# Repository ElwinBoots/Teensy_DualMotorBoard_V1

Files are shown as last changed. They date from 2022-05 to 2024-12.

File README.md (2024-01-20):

This project aims to deliver high performance (fast loops > 40 kHz, fast motion, and small following errors) brushless motor control.

## Videos in action 
See: https://www.youtube.com/@elwinboots2614

## Hardware 
- 1 Simple custom PCB for making connections
- 1 Teensy 4.1
- 2 DRV8301 motor drive boards, see Aliexpress
- 2 BLDC motors (sensorless or ABI encoders)
- 4 Pololu ACS711EX current sensor boards (drive boards have low side sensors. Prefer to use these instead to have in line sensing)

## Firmware
See firmware folder. Almost all code can be found in Firmware.ino. 

### Software to build firmware
"Old" Arduino IDE
- Arduino IDE 1.8.19 https://www.arduino.cc/en/software (Legacy IDE)
- Teensyduino https://www.pjrc.com/teensy/td_download.html (Follow the "Arduino 1.8.x Software Development" steps)
Or,
"New" Arduino IDE:
- Arduino IDE https://www.arduino.cc/en/software (current version: 2.2.1)
- Teensyduino https://www.pjrc.com/teensy/td_download.html (Follow the "Arduino 2.0.x Software Development" steps
 
If you want to test with 1 or 0 DRV8301 boards connected, search for the line: SPI_init( SSPIN ); and/or SPI_init( SSPIN2 ); and comment them out. With these lines commented the firmware and software can run without boards. With these lines the board waits for the DRV8301 boards, before continuing to boot.

Almost all parameters are defined in defines.h. All of these are accessible (read and write) from the host pc using the software provided. 

To add a variable and make it accessible from the PC:
1. Add parameter in defines.h 
2. run "gentracefile (Run this to update trace.h).bat". 
3. Compile and download Firmware.ino in Arduino IDE

Note: I use the 816 Mhz (overclock) option in the CPU speed menu.

## Software
- Python 3.x
- Spyder
- Code in Software folder

### To install: 
1. Download latest version of Python: https://www.python.org/downloads/
2. Install Python
3. In a command window, run `pip install spyder`
4. Run Spyder (C:\Users\XXX\AppData\Local\Programs\Python\PythonXXX\Scripts\spyder.exe)

### To use: 
1. In Spyder, run first cell (ctrl + enter) in test_object.py (for any missing modules, run `pip install <modulename>` in a cmd window.
2. When a Teensy is found with the correct firmware, you should get: "Connected to Teensy on COMX with serial number: XXXXXXXX."
3. Check that the LED on the Teensy is off. If it is still on, make check connection and power to DRV8301 boards, or comment out SPI_init( SSPIN ); and/or SPI_init( SSPIN2 ) to test without DRV8301 boards.
4. Now you can type `motor` in the IPython console, and it should show all parameters:\
afbeelding

5. To see for example only the configuration of motor 1, you can type `motor.conf1`:\
afbeelding

6. To retreive a single variable, just type the variable name and click enter. Example: `motor.state1.encoderPos1`. Note that you can use `tab` to autocomplete the name of a variable.
7. To set a variable, simply write a value to it. Example: `motor.conf1.commutationoffset = 0`, or use `m.setpar('motor.conf1.commutationoffset',0)`\
afbeelding\
The setting of variables is fast. Almost 20000 values can be written in 1 second when writing one by one (even more when using arrays):\
afbeelding

### Tracing
To trace variables/signals: 
1. Use m.setTrace() to select signals. Example: `m.setTrace([ 'motor.state1.emech' , 'motor.state1.rmech' , 'motor.state1.ymech' ])`
2. Use `df = m.trace(2)` to trace for 2 seconds.
3. To plot, use `df.plot()`

Note1: By default tracing occurs at the full sample rate. Up to 50 signals at 60 kHz is possible. Downsampling is also possible to reduce load.\
Note2: All communication is in binary. This means that no precision is lost in the tracing.

### Tracing (background)
For non-blocking tracing of variables/signals:
1. Use m.setTrace() to select signals. Example: `m.setTrace([ 'motor.state1.emech' , 'motor.state1.rmech' , 'motor.state1.ymech' ])`
2. Use `m.tracebg( )` to start a background trace.
3. Use `df = m.stoptracegetdata()` to stop the trace and get the data
4. To plot, use `df.plot()`

Note: during the tracing you can still set variables. You can however not retrieve other variables.

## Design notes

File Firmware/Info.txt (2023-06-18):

/*
  See https://nl.mathworks.com/help/mcb/ref/mtpacontrolreference.html for a PMSM model

  vd = id*R + dλd/dt − ωe * Lq * iq
  vq = iq*R + dλq/dt + ωe * Ld * id + ωe * λpm
  λd = Ld * id + λpm
  λq = Lq * iq
  Te = 1.5* N_pp * (λpm * iq+(Ld− Lq) * id * iq)

  vd is the d-axis voltage (Volts).
  vq is the q-axis voltage (Volts).
  id is the d-axis current (Amperes).
  iq is the q-axis current (Amperes).
  R is the stator phase winding resistance (Ohms).
  λpm is the permanent magnet flux linkage (Weber).
  λd is the d-axis flux linkage (Weber).
  λq is the q-axis flux linkage (Weber).
  ωe is the electrical speed corresponding to frequency of stator voltages (Radians/ sec).
  Ld is the d-axis winding inductance (Henry).
  Lq is the q-axis winding inductance (Henry).
  Te is the electromechanical torque produced by the PMSM (Nm).
  N_pp is the number of motor pole pairs.

  Te = 1.5* N_pp * (λpm * iq+(Ld− Lq) * id * iq)
  id = 0 -> Te = 1.5 * N_pp * λpm * iq [Nm]

  Kt_Nm_Apeak = 1.5 * N_pp * λpm                                            [Nm/Apeak]
  Kt_Nm_Arms = sqrt(2) * Kt_Nm_Apeak                                        [Nm/Arms]

  λpm = Kt_Nm_Apeak / (1.5 * N_pp) = Kt_Nm_Arms / (sqrt(2) * 1.5 * N_pp )   [Weber]

  Ke_phase_0_peak = N_pp * λpm
*/

/*
  With 1 motor:

  M:
  FLEXPWM2 4 5 6
  {1, M(2, 0), 1, 1},  // FlexPWM2_0_A   4  // EMC_06
  {1, M(2, 1), 1, 1},  // FlexPWM2_1_A   5  // EMC_08
  {1, M(2, 2), 1, 2},  // FlexPWM2_2_A   6  // B0_10

  Encoders:
  E1:
  0 1 3

  E2:
  30 31 33

  For two motors:

  M1:
  FLEXPWM4 22 23 2
  {1, M(4, 0), 1, 1},  // FlexPWM4_0_A  22  // AD_B1_08    --> M1 Phase B
  {1, M(4, 1), 1, 1},  // FlexPWM4_1_A  23  // AD_B1_09    --> M1 Phase C 
  {1, M(4, 2), 1, 1},  // FlexPWM4_2_A   2  // EMC_04      --> M1 Phase A

  M2:
  FLEXPWM2 4 5 6
  {1, M(2, 0), 1, 1},  // FlexPWM2_0_A   4  // EMC_06      --> M2 Phase C
  {1, M(2, 1), 1, 1},  // FlexPWM2_1_A   5  // EMC_08      --> M2 Phase B
  {1, M(2, 2), 1, 2},  // FlexPWM2_2_A   6  // B0_10       --> M2 Phase A

  Encoders:
  E1:
  0 1 3

  E2:
  30 31 33

  teensy 4.1 has 0..41 full size pins.

  Encoder possible on:
  0, 1, 2, 3, 4, 5, 7, 30, 31, 33, 36 and 37.
  WARNING! Pins 0, 5 and 37 share the same internal crossbar connections and are as such exclusive...pick one or the other.

//There are 4 hardware quadrature encoder channels available the Teensy 4.x.
//The Teensy 4.1 Encoders are supported on pins: 0, 1, 2, 3, 4, 5, 7, 30, 31, 33, 36 and 37.
//WARNING! Pins 0, 5 and 37 share the same internal crossbar connections and are as such exclusive...pick one or the other.
//Same thing applies to pins 1 / 36 and 5 / 37.

  ADC channel, pin numbers

    Note: 0 to 13 is same as 14 to 27. Do not try to use these for analog in!
        7,      // 0/A0  AD_B1_02   ENC1_A
        8,      // 1/A1  AD_B1_03   ENC1_B
        12,     // 2/A2  AD_B1_07   M1 out A INH-A
        11,     // 3/A3  AD_B1_06   ENC1_I
        6,      // 4/A4  AD_B1_01   M2 out C INH-C2
        5,      // 5/A5  AD_B1_00   M2 out B INH-B2
        15,     // 6/A6  AD_B1_10   M2 out A INH-A2
        0,      // 7/A7  AD_B1_11   M2 Ia              --> Orignial design --> Doesn't work
        13,     // 8/A8  AD_B1_08   M2 Ib              --> Orignial design --> Doesn't work
        14,     // 9/A9  AD_B1_09   M2 Ic              --> Orignial design --> Doesn't work
        255,  // 10/A10 AD_B0_12   -
        255,  // 11/A11 AD_B0_13    SDI (SPI)
        3,      // 12/A12 AD_B1_14  SDO (SPI)
        4,      // 13/A13 AD_B1_15  SCLK (SPI)

        7,      // 14/A0  AD_B1_02  M1 Ic
        8,      // 15/A1  AD_B1_03  M1 Ib
        12,     // 16/A2  AD_B1_07  M1 Ia
        11,     // 17/A3  AD_B1_06  M1 Vbus
        6,      // 18/A4  AD_B1_01  M1 EMF-A
        5,      // 19/A5  AD_B1_00  M1 EMF-B
        15,     // 20/A6  AD_B1_10  M1 EMF-C
        0,      // 21/A7  AD_B1_11  M2 Vbus
        13,     // 22/A8  AD_B1_08  M1 out C INH-C
        14,     // 23/A9  AD_B1_09  M1 out B INH-B
        255,    // 24/A10 AD_B0_12  M2 EMF-A  --> Exchanged for M2 Ia
        255,    // 25/A11 AD_B0_13  M2 EMF-B
        3,      // 26/A12 AD_B1_14  M2 EMF-C  --> Exchanged for M2 Ib
        4,      // 27/A13 AD_B1_15  M2 nOCTW
        255,    // 28               M2 PWRGD
        255,    // 29
        255,    // 30               ENC2_A
        255,    // 31               ENC2_B
        255,    // 32
        255,    // 33               ENC2_I
        255,    // 34               M1 EN-GATE
        255,    // 35               M1 nSCS
        255,    // 36               M1 nFAULT
        255,    // 37               M1 nOCTW
        1,      // 38/A14 AD_B1_12  M1 PWRGD
        2,      // 39/A15 AD_B1_13  M2 EN-GATE
        9,      // 40/A16 AD_B1_04  M2 nSCS
        10,     // 41/A17 AD_B1_05  M2 nFAULT

    Actual chain:
        12,     // 16/A2  AD_B1_07  M1 Ia
        8,      // 15/A1  AD_B1_03  M1 Ib

        1,      // 24/A10 AD_B0_12  M2 EMF-A  --> Exchanged for M2 Ia  // Analog channel 1 input 1 NOTE: only on ADC1
        3,      // 26/A12 AD_B1_14  M2 EMF-C  --> Exchanged for M2 Ib  // Analog channel 2 input 3 NOTE: only on ADC2

        11,     // 17/A3  AD_B1_06  M1 Vbus
        0,      // 21/A7  AD_B1_11  M2 Vbus
  */

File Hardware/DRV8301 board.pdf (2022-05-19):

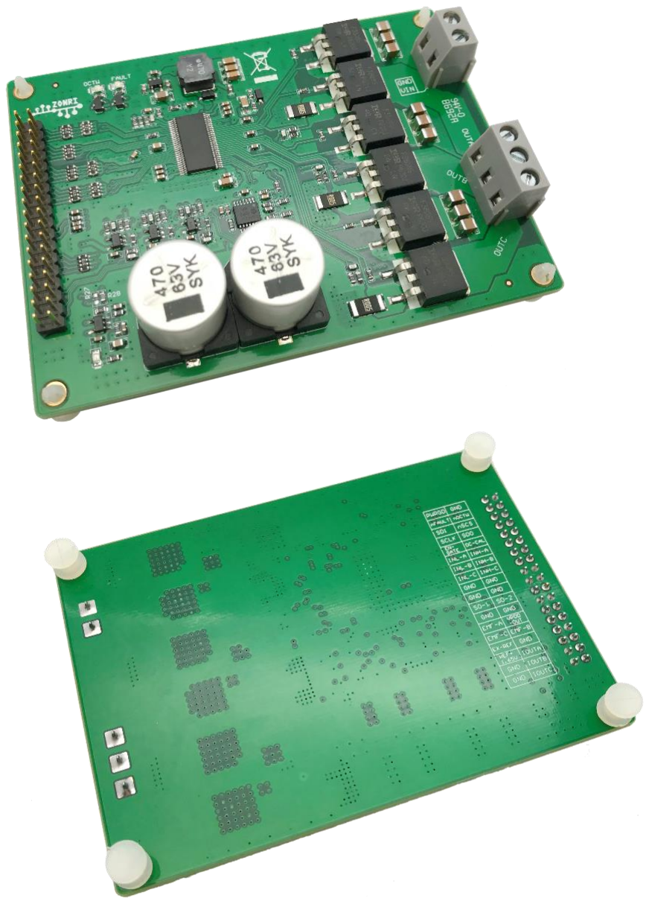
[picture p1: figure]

# DRV8301 电机驱动模块说明书

概述:

# - 额定电源输入范围:5.5V – 45Vdc，输出额定驱动电流 15A（室温下无安装散热器）。 - 板载三相外部电流放大电路，增益为 12.22，全幅度电流为±27A。 - 板载三相反电动势采样电路与电源采样电路，信号衰减比例为 5.1/73.1。 - 可选三相差分电流放大器参考电平，可与 5V 或其他电平系统连接。 - 保留并具备 DRV8301 内部双路放大器输出。 - 三路外部电流差分放大器支持 ST FOC 库应用。 - 支持 BLDC 无感无刷电机驱动应用开发。

# - 四层 FR4 PCB 板，符合 ROHS。

目录：

# 1、DRV8301 电机驱动模块接口图 2、DRV8301 电机驱动模块原理框图与应用说明。 3、DRV8301 电机驱动模块接口说明 4、DRV8301 电机驱动模块 PCB 版图 5、DRV8301 电机驱动模块 PCB 位图 6、DRV8301 电机驱动模块原理图

# 版权所有：ZonRi Technology Co.,Ltd.（编：18.4.10.01.04）

# ( 本文档发布时经过核查，此后的内容变动或版本更新恕不另行通知 )

# 1、DRV8301 电机驱动模块接口图

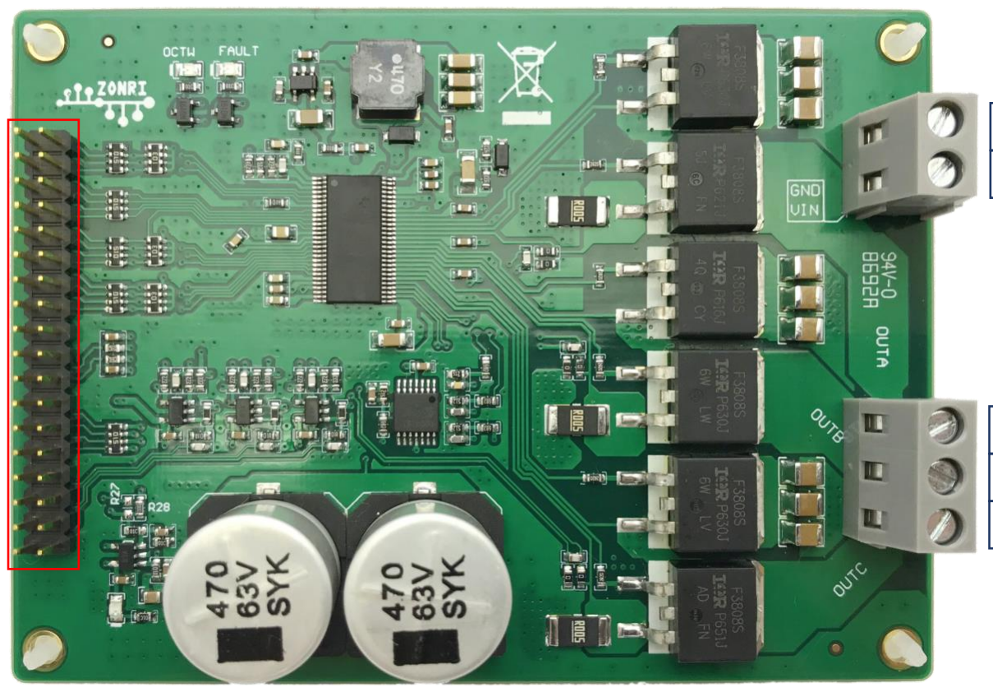
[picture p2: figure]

# GND VIN

# OUTA OUTB OUTC

GND | PWRGD
nOCTW | nFAULT
nSCS | SDI
SDO | SCLK
DC-CAL | EN-GATE
INH-A | INL-A
INH-B | INL-B
INH-C | INL-C
GND | GND
GND | GND
SO-2 | SO-1
GND | GND

# VPDD-O

EMF-B | EMF-C
GND | EX-REF
IOUTA | REF+1.65V
IOUTB | GND
IOUTC | GND

# EMF-A

# 2、DRV8301 电机驱动模块原理框图与应用说明

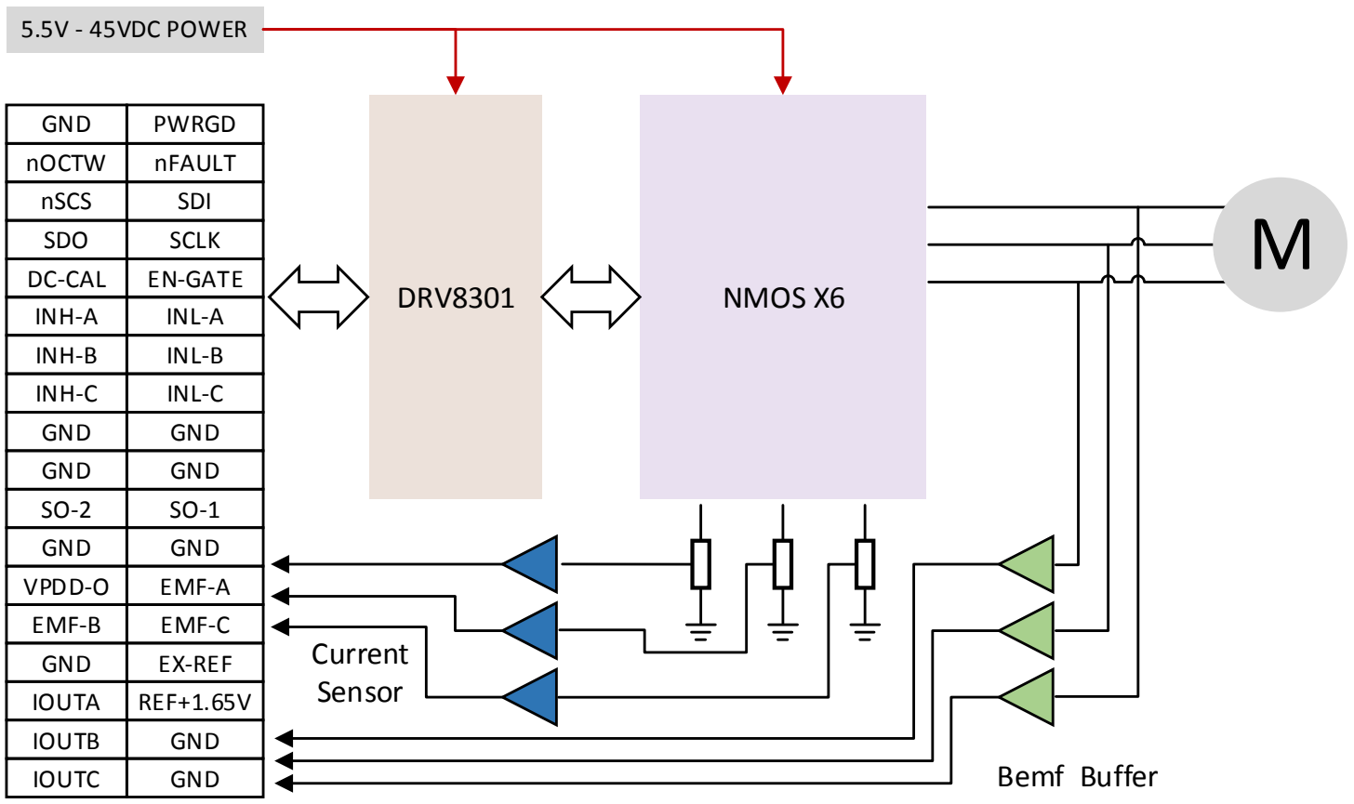
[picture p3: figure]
DRV8301; NMOS X6; Bemf Buffer; Current Sensor; GND; nOCTW; nSCS; SDO; DC-CAL INH-A; INH-B; INH-C; VPDD-O; EMF-B; IOUTA; IOUTB; IOUTC; PWRGD; nFAULT; SDI; SCLK; EN-GATE INL-A; INL-B; INL-C; EMF-A; EMF-C; EX-REF; REF+1.65V; 5.5V - 45VDC POWER

# 3、DRV8301 电机驱动模块接口说明

# GND

# nOCTW

# nSCS

# SDO

# DC-CAL

# INH-A

# INH-B

# INH-C

# PWRGD

# nFAULT

# SDI

# SCLK

# EN-GATE

# INL-A

# INL-B

# INL-C

SO-1 | DRV8301内部放大器1输出
EMF-A | A 相反电动势输出，幅值=5.1/73.1 EMF

# GND

# nOCTW

# nSCS

# SDO

# DRV8301内部放大器输入短接切换信号

# A 相高边MOS 开关信号

# B 相高边MOS 开关信号

# C 相高边MOS 开关信号

# DRV8301 DC-DC工作指示信号

# DRV8301异常指示信号（详见DRV8301 DATASHEET)

# SDI

# SCLK

# DRV8301驱动使能，高电平使能。

# A 相低边MOS 开关信号

# B 相低边MOS 开关信号

# C 相低边MOS 开关信号

# IOUTC

# C 相电流信号输出

SO-2

# VPDD-O

EMF-B | B 相反电动势输出，幅值=5.1/73.1 EMF
IOUTA | A 相电流信号输出
IOUTB | B 相电流信号输出

# DRV8301内部放大器2输出

# 电源电压信号输出，幅值=5.1/73.1 VPDD

# EMF-C

# EX-REF

# REF+1.65V

# C 相反电动势输出，幅值=5.1/73.1 EMF

# 电流差分放大器参考电平，可通过R27、R28选择 内部或外部参考电平，内部参考电平为3.3V，即 当相电流信号输出为1.65V时，代表相电流为0。 设置例子：当需要设置以2.5V为0电流电平信号 是，需要将此引脚连接至5V电平，并R28空焊同 时R27焊接0R电阻。

# 外部差分电流放大器参考电平输出，当使用板内 3.3V参考电平时，此引脚输出1/2参考电平幅值，

即1.65V

# 4、DRV8301 电机驱动模块 PCB 版图

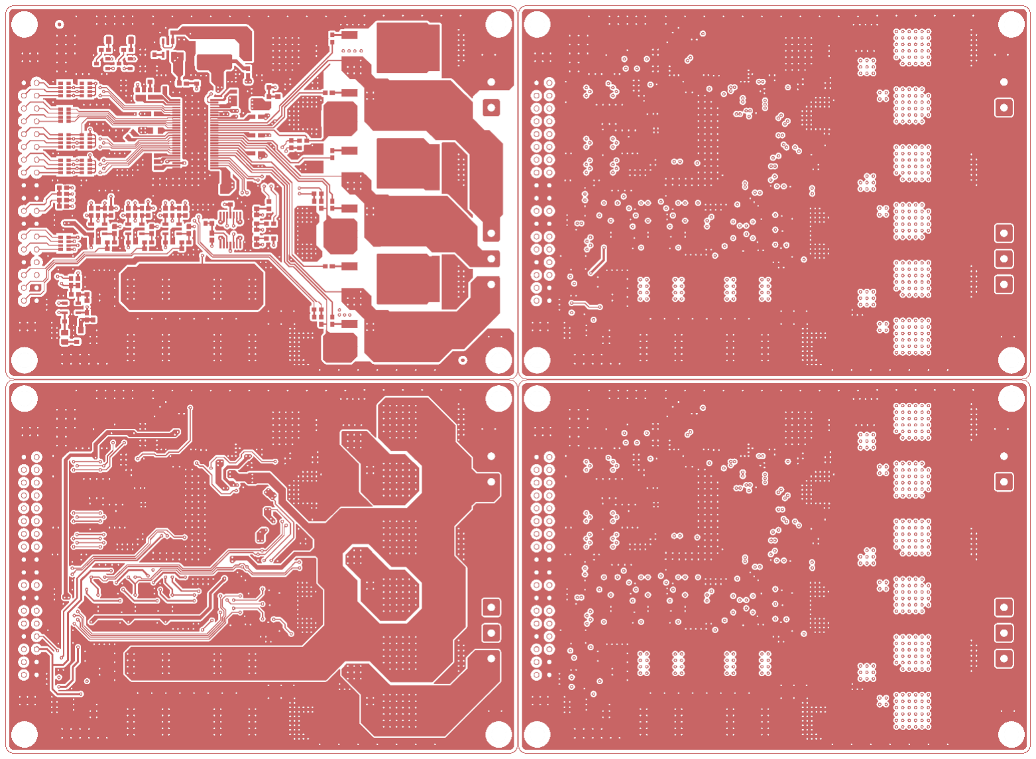
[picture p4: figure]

# 5、DRV8301 电机驱动模块 PCB 位图（与原理图对应）&尺寸图

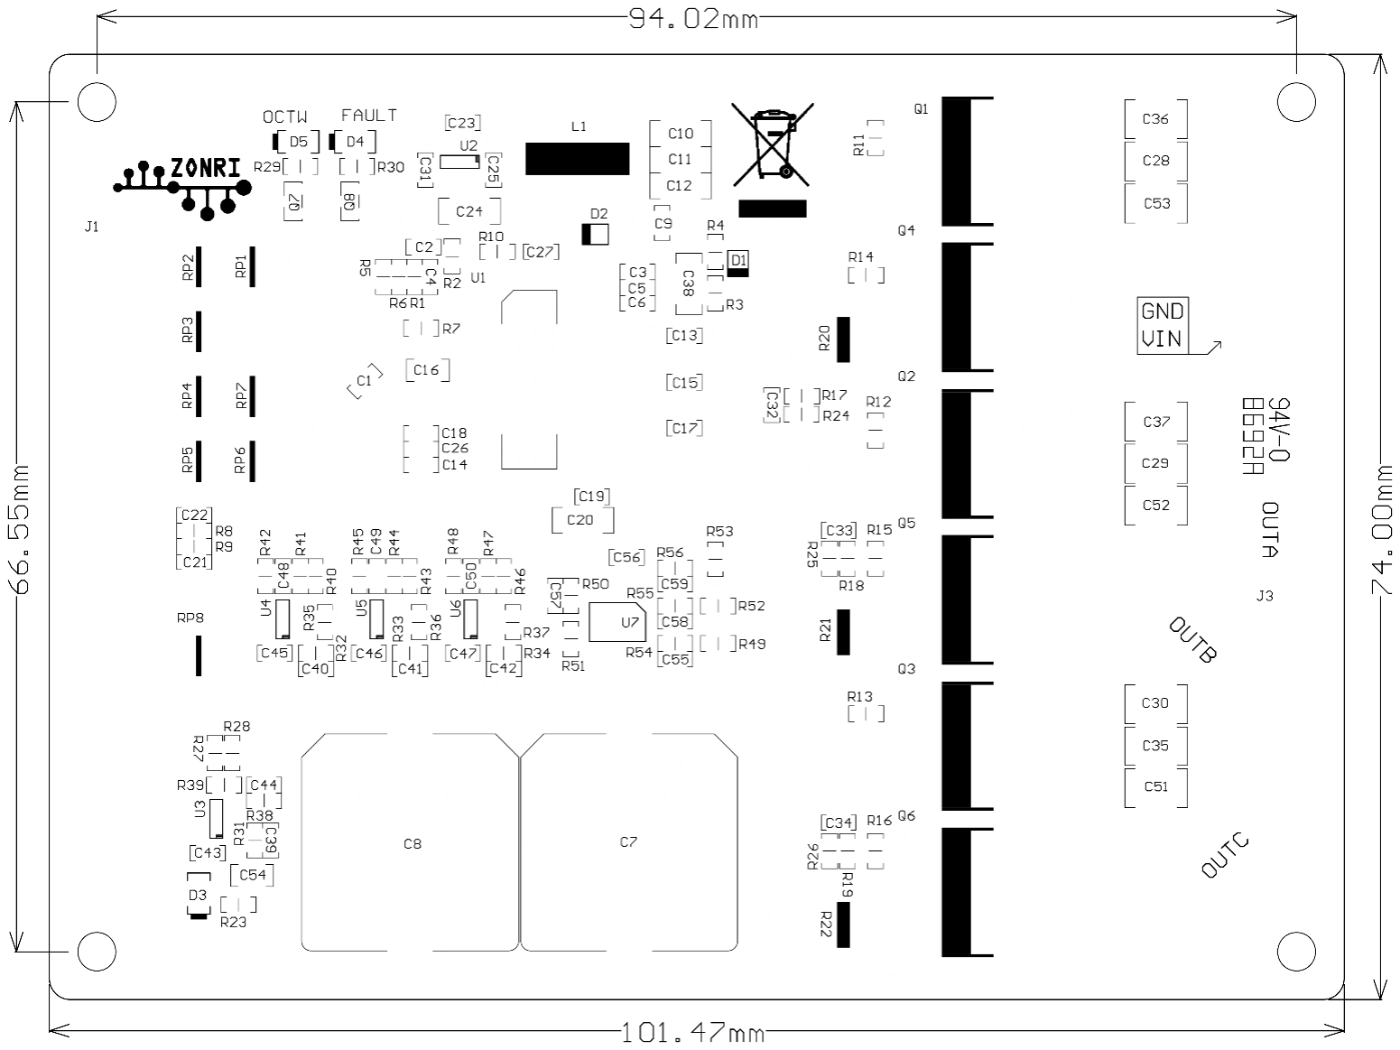
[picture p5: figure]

# 6、DRV8301 电机驱动模块原理图

AGND 28 | PVDD1 | 29 SP2 | 30 SN2 | 31 SP1 | 32 SN1 | 33 SL_C | 34 GL_C | 35 SH_C | 36 GH_C | 37 BST_C | 38 SL_B | 39 GL_B | 40 SH_B | 41 GH_B | 42 BST_B | 43 SL_A | 44 GL_A | 45 SH_A | 46 GH_A | 47 BST_A | 48 VDD_SPI | 49 PH | 50 PH | 51 BST_BK | 52 PVDD2 | 53 PVDD2 | 54 EN_BUCK | 55 SS_TR | 56

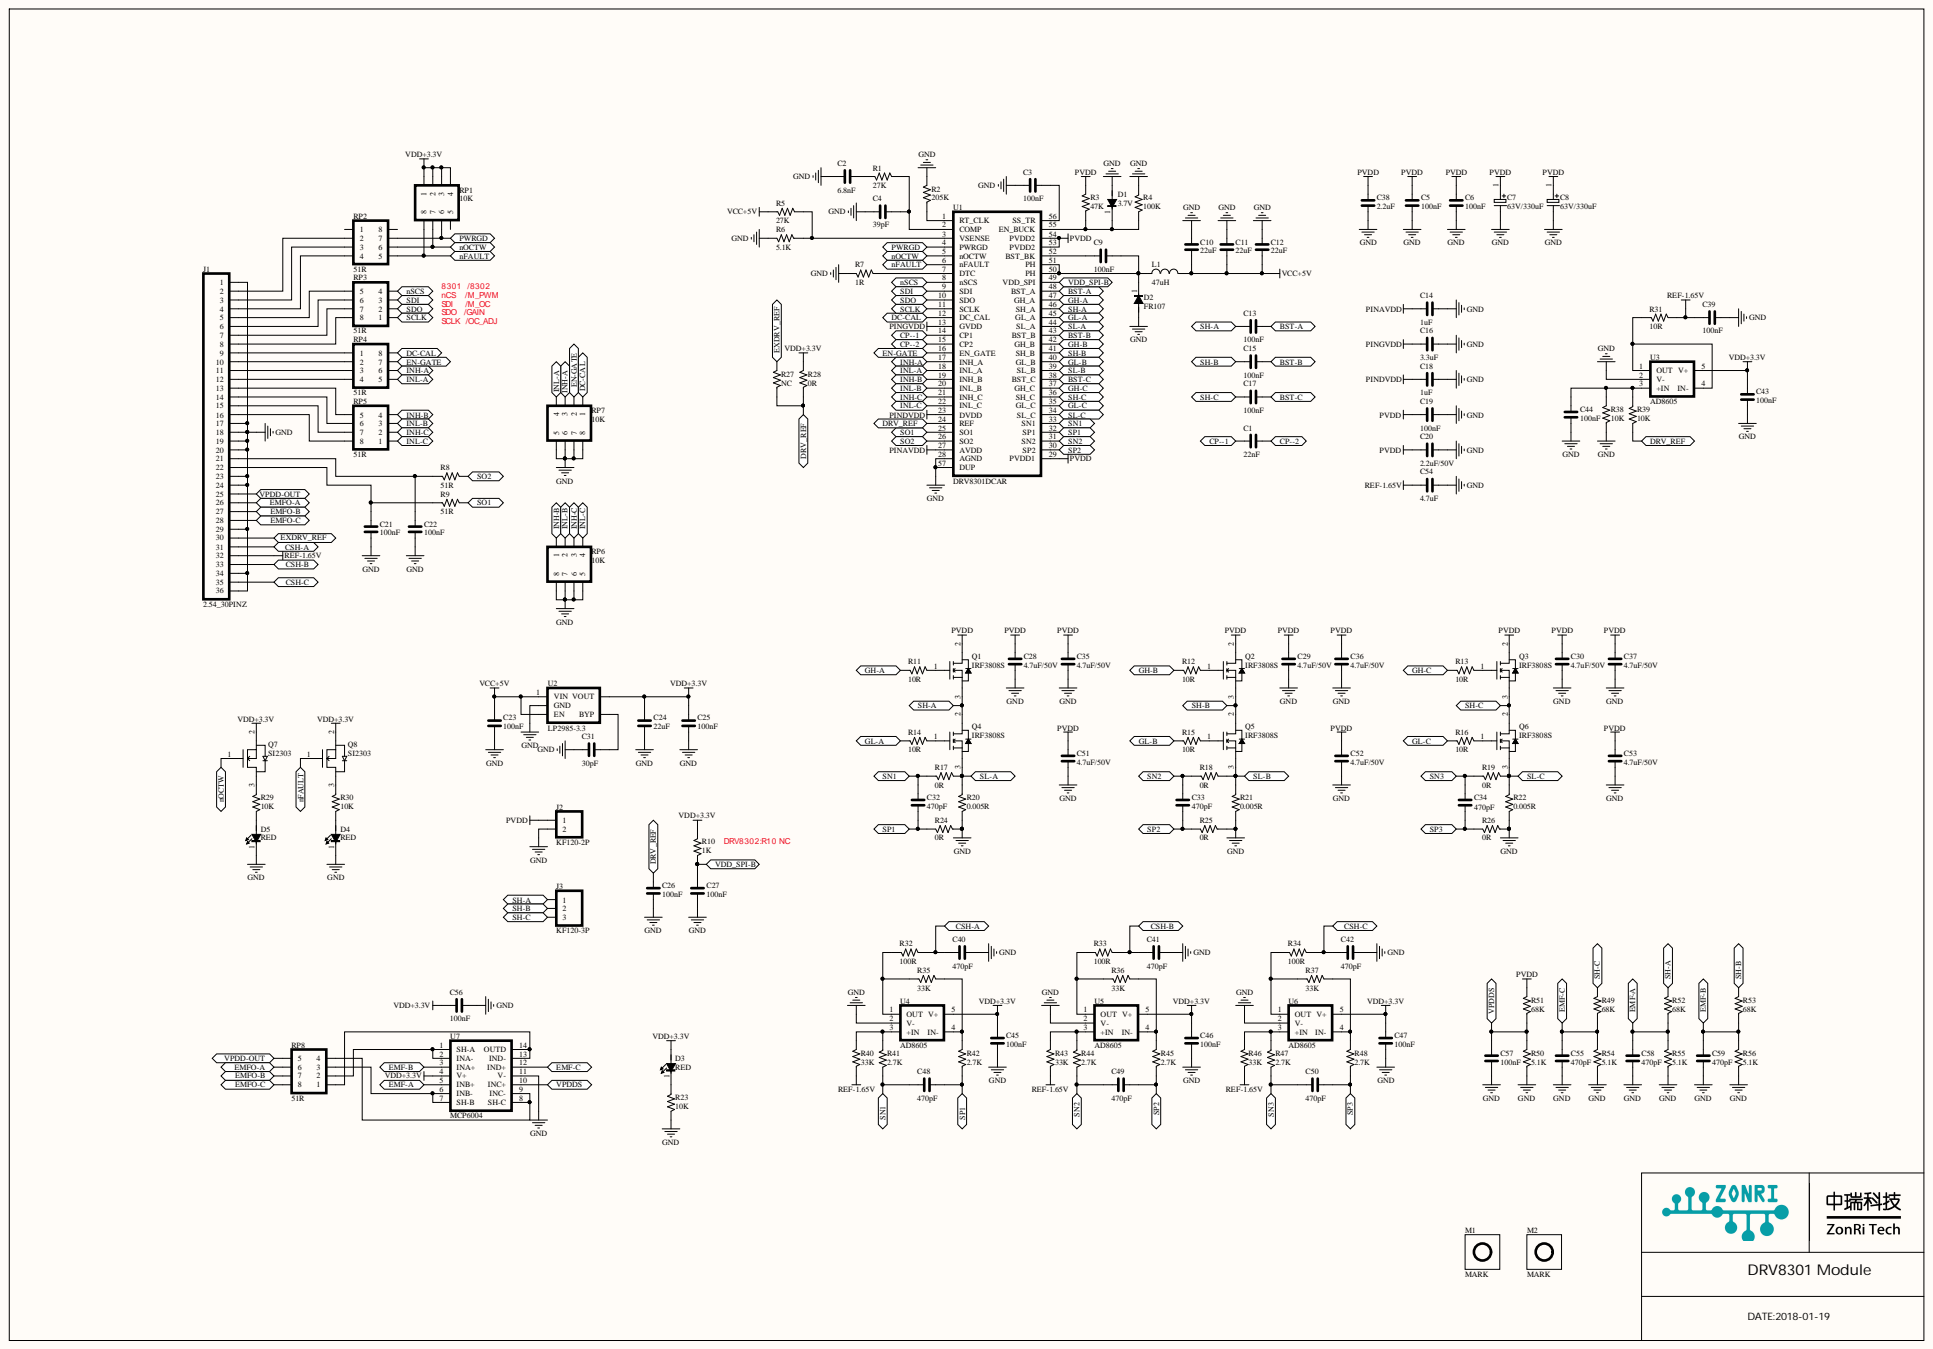
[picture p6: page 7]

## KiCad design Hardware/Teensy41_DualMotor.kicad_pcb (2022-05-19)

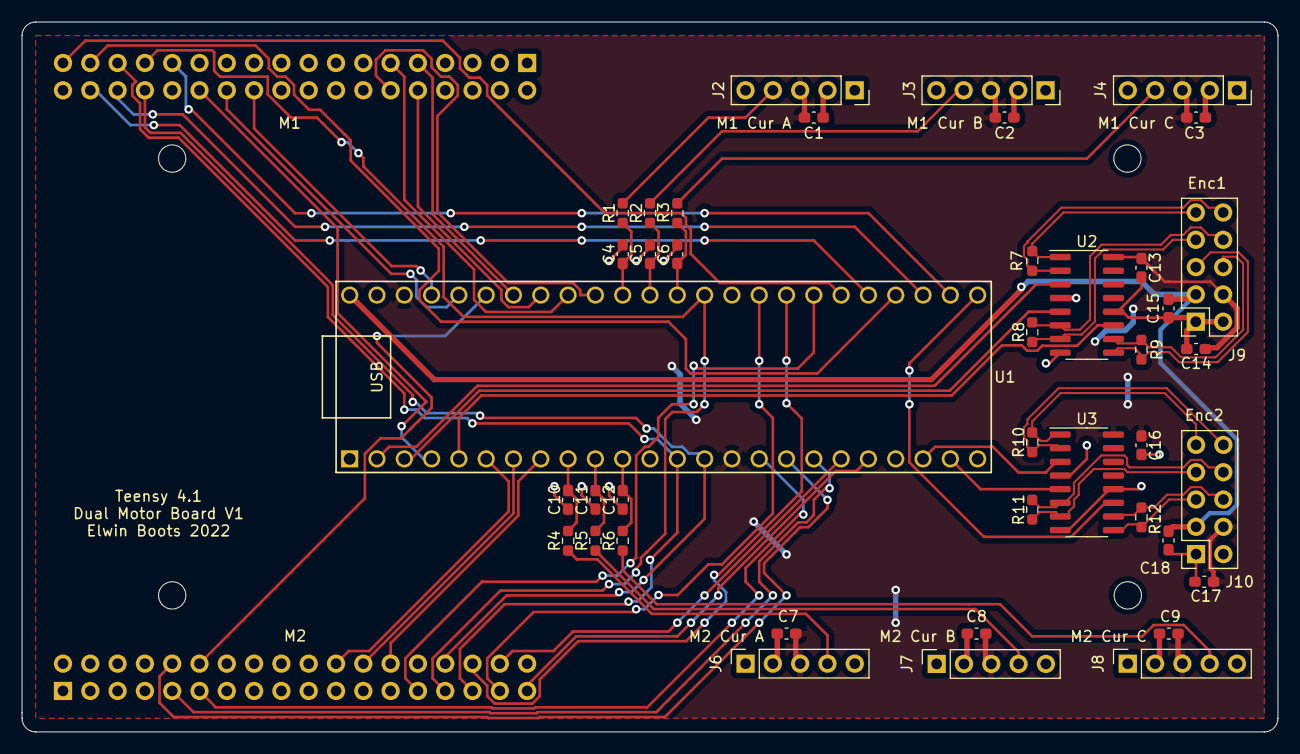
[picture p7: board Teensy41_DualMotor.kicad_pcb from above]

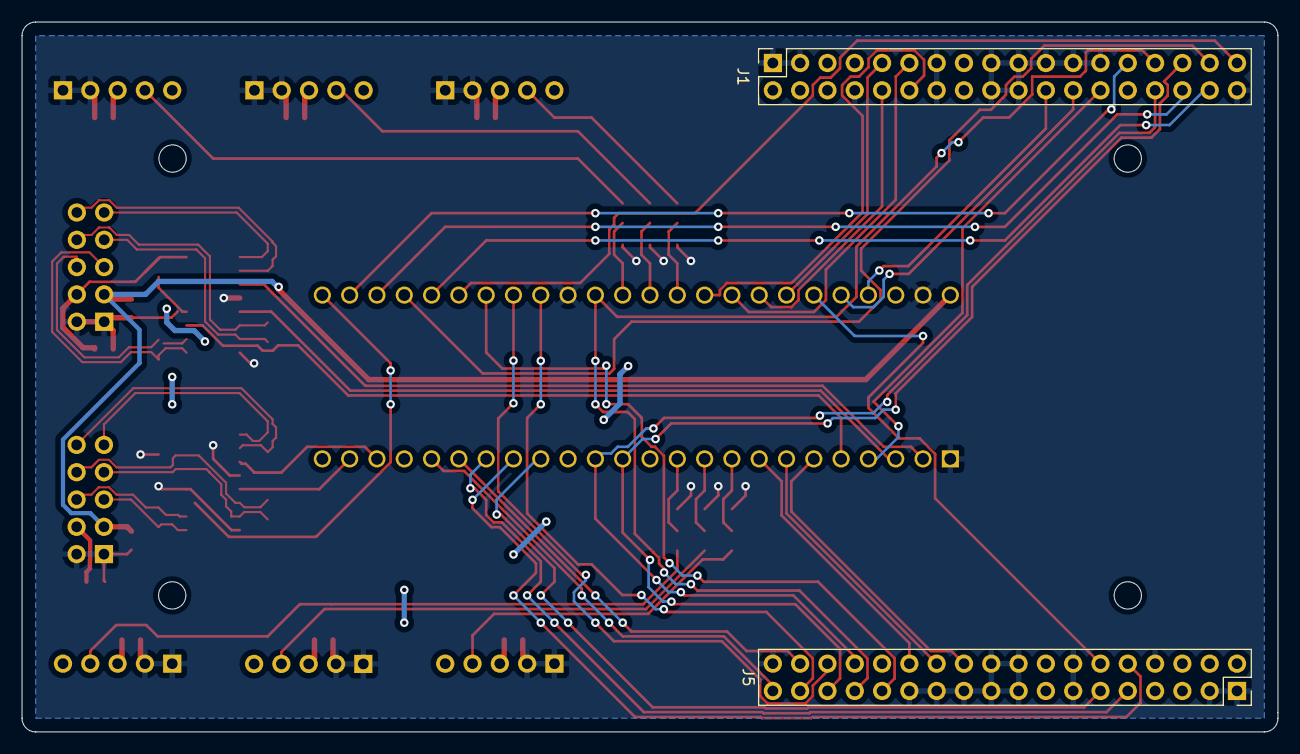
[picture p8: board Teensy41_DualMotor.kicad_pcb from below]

Board: 2 copper layers, 116.8 x 66.0 mm, 43 parts (2 on the bottom side), 60 nets.

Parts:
C1, C2, C3, C7, C8, C9, C13, C14, C15, C16, C17, C18: 0.1u; C_0603_1608Metric_Pad1.08x0.95mm_HandSolder
C4, C5, C6, C10, C11, C12: 15n; C_0603_1608Metric_Pad1.08x0.95mm_HandSolder
J1, J5: Conn_02x18_Odd_Even; PinSocket_2x18_P2.54mm_Vertical
J2, J3, J4, J6, J7, J8: Conn_01x05; PinSocket_1x05_P2.54mm_Vertical
J9, J10: Conn_02x05_Odd_Even; PinSocket_2x05_P2.54mm_Vertical
R1, R2, R3, R4, R5, R6: 1k; R_0603_1608Metric_Pad0.98x0.95mm_HandSolder
R7, R8, R9, R10, R11, R12: 120; R_0603_1608Metric_Pad0.98x0.95mm_HandSolder
U1: Teensy4.1; Teensy41
U2, U3: AM26LV32xD; SOIC-16_3.9x9.9mm_P1.27mm

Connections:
+3V3: C1.2, C2.2, C3.2, C7.2, C8.2, C9.2, C13.2, C14.2, C16.2, C17.2, J2.3, J3.3, J4.3, J6.3, J7.3, J8.3, J9.4, J10.4, U1.15 (3V3), U1.46 (3V3), U2.16 (VDD), U3.16 (VDD)
+5V: C15.2, C18.2, J9.3, J10.3, U1.48 (VIN)
EMF-A: J1.11, U1.40 (18_A4_SDA)
EMF-A2: J5.11, U1.16 (24_A10_TX6_SCL2)
EMF-B: J1.10, U1.41 (19_A5_SCL)
EMF-B2: J5.10, U1.17 (25_A11_RX6_SDA2)
EMF-C: J1.9, U1.42 (20_A6_TX5_LRCLK1)
EMF-C2: J5.9, U1.18 (26_A12_MOSI1)
EN-GATE: J1.27, U1.26 (34_RX8)
EN-GATE2: J5.27, U1.31 (39_MISO1_OUT1A)
ENC1_A: U1.2 (0_RX1_CRX2_CS1), U2.3 (1Y)
ENC1_A+: J9.10, R7.1, U2.2 (1A)
ENC1_A-: J9.9, R7.2, U2.1 (1B)
ENC1_B: U1.3 (1_TX1_CTX2_MISO1), U2.5 (2Y)
ENC1_B+: J9.8, R8.1, U2.6 (2A)
ENC1_B-: J9.7, R8.2, U2.7 (2B)
ENC1_I: U1.5 (3_LRCLK2), U2.11 (3Y)
ENC1_I+: J9.6, R9.1, U2.10 (3A)
ENC1_I-: J9.5, R9.2, U2.9 (3B)
ENC2_A: U1.22 (30_CRX3), U3.3 (1Y)
ENC2_A+: J10.10, R10.1, U3.2 (1A)
ENC2_A-: J10.9, R10.2, U3.1 (1B)
ENC2_B: U1.23 (31_CTX3), U3.5 (2Y)
ENC2_B+: J10.8, R11.1, U3.6 (2A)
ENC2_B-: J10.7, R11.2, U3.7 (2B)
ENC2_I: U1.25 (33_MCLK2), U3.11 (3Y)
ENC2_I+: J10.6, R12.1, U3.10 (3A)
ENC2_I-: J10.5, R12.2, U3.9 (3B)
GND: C1.1, C2.1, C3.1, C4.2, C5.2, C6.2, C7.1, C8.1, C9.1, C10.2, C11.2, C12.2, C13.1, C14.1, C15.1, C16.1, C17.1, C18.1, J1.1, J1.3, J1.8, J1.13, J1.14, J1.17, J1.18, J1.19, J1.20, J1.21, J1.23, J1.25, J1.36, J2.1, J2.2, J3.1, J3.2, J4.1, J4.2, J5.1, J5.3, J5.8, J5.13, J5.14, J5.17, J5.18, J5.19, J5.20, J5.21, J5.23, J5.25, J5.36, J6.1, J6.2, J7.1, J7.2, J8.1, J8.2, J9.1, J9.2, J10.1, J10.2, U1.1 (GND), U1.34 (GND), U1.47 (GND), U2.4 (G), U2.8 (GND), U2.12 (~G), U3.4 (G), U3.8 (GND), U3.12 (~G)
INH-A: J1.26, U1.4 (2_OUT2)
INH-A2: J5.26, U1.8 (6_OUT1D)
INH-B: J1.24, U1.44 (22_A8_CTX1)
INH-B2: J5.24, U1.7 (5_IN2)
INH-C: J1.22, U1.45 (23_A9_CRX1_MCLK1)
INH-C2: J5.22, U1.6 (4_BCLK2)
I_PH_A: J2.4, R1.1
I_PH_A2: J6.4, R4.1
I_PH_A2_Filt: C10.1, R4.2, U1.9 (7_RX2_OUT1A)
I_PH_A_Filt: C4.1, R1.2, U1.38 (16_A2_RX4_SCL1)
I_PH_B: J3.4, R2.1
I_PH_B2: J7.4, R5.1
I_PH_B2_Filt: C11.1, R5.2, U1.10 (8_TX2_IN1)
I_PH_B_Filt: C5.1, R2.2, U1.37 (15_A1_RX3_SPDIF_IN)
I_PH_C: J4.4, R3.1
I_PH_C2: J8.4, R6.1
I_PH_C2_Filt: C12.1, R6.2, U1.11 (9_OUT1C)
I_PH_C_Filt: C6.1, R3.2, U1.36 (14_A0_TX3_SPDIF_OUT)
PWRGD: J1.35, U1.30 (38_CS1_IN1)
PWRGD2: J5.35, U1.20 (28_RX7)
SCLK: J1.29, J5.29, U1.35 (13_SCK_LED)
SDI: J1.31, J5.31, U1.13 (11_MOSI_CTX1)
SDO: J1.30, J5.30, U1.14 (12_MISO_MQSL)
VPDD-O: J1.12, U1.39 (17_A3_TX4_SDA1)
VPDD-O2: J5.12, U1.43 (21_A7_RX5_BCLK1)
nFAULT: J1.33, U1.28 (36_CS)
nFAULT2: J5.33, U1.33 (41_A17)
nOCTW: J1.34, U1.29 (37_CS)
nOCTW2: J5.34, U1.19 (27_A13_SCK1)
nSCS: J1.32, U1.27 (35_TX8)
nSCS2: J5.32, U1.32 (40_A16)

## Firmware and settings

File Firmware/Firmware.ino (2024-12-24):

#include <math.h>
#include <arm_math.h>
#include <SPI.h>

#include "Biquad.h"
#include "muziek.c"
#include "QuadEncoder.h"
#include "MotionProfile.h"
#include "defines.h"
#include "trace.h"

Biquad *Biquads1[6];
Biquad *Biquads2[6];
MotionProfile *SPprofile1 = new MotionProfile( 0 , 0.0005 , 0.0193 , 0 , 3.14 , 157 , 7853 , 15632147 , 1 / (2.0f * F_PWM) );
MotionProfile *SPprofile2 = new MotionProfile( 0 , 0.0005 , 0.0193 , 0 , 3.14 , 157 , 7853 , 15632147 , 1 / (2.0f * F_PWM) );
QuadEncoder Encoder1(1, 0, 1 , 0 , 3);   //Encoder 1 on pins 0 and 1, index on pin 3
QuadEncoder Encoder2(2, 30, 31 , 0 , 33);//Encoder 2 on pins 30 and 31, index on pin 33

bool sendnames = false;

void initparams( motor_total_t* m ) {
  m->conf.Ts = 1e6 / (2 * F_PWM);
  m->conf.fs = 2 * F_PWM;
  m->conf.T = m->conf.Ts / 1e6;
  m->conf.Busadc2Vbus = 1 / 4095.0 * 3.3 * ((68.3 + 5.05) / 5.05); //5.1 changed to 5.05 to improve accuracy. May differ board to board.
  m->conf.V_Bus = 24; //Bus Voltage
  m->conf.Ndownsample = 1;

  m->state1.OutputOn = false;
  m->state2.OutputOn = false;

  initmotor( &m->conf1 , &m->state1);
  initmotor( &m->conf2 , &m->state2);

  m->state.lfsr = 0xACE1u;
  m->state.ss_f = 1;
}

void initmotor( mot_conf_t* m , mot_state_t* state ) {
  m->maxDutyCycle = 0.99;
  m->adc2A = 1 / 0.09; //With linear hal current sensors ACS711 (31A or 15.5A): These allow for 2 measurements per PWM cycle

  m->enccountperrev = 20000;
  m->enc2rad = twoPI / m->enccountperrev;
  m->I_max = 15; //Max current (peak of the sine wave in a phase)
  m->max_edeltarad = 0.25f * M_PI;

  m->maxerror = 0.5;

  m->T_max = 1;

  //Motor parameters
  m->N_pp = 4; //Number of pole pairs
  m->Ld = 9e-3; //[Henry] Ld induction: phase-zero
  m->Lq = 10e-3; //[Henry] Lq induction: phase-zero
  m->Lambda_m = 0.01; //[Weber] Note: on the fly changes of Kt do not adjust this value!
  m->Kp = 0;

  m->hfi_c_lowpass = 0.19; //HFI lowpass (0.19 gives 2000 Hz at 60 kHz sampling: c = 1 - exp(-2000*2*pi*1/60000))

  m->hfi_truncate_rad = 1;
}

void setup() {
  initparams( &motor );

  for (int i = 0; i < 6; i++)
  {
    Biquads1[i] = new Biquad( bq_type_lowpass , 0 , 0.7, motor.conf.fs);;
    Biquads2[i] = new Biquad( bq_type_lowpass , 0 , 0.7, motor.conf.fs);;
  }

  pinMode( ENGATE , OUTPUT);
  digitalWrite( ENGATE , 1); // To be updated!
  SPI_init( SSPIN );  // Only for DRV8301.

  pinMode( ENGATE2 , OUTPUT);
  digitalWrite( ENGATE2 , 1); // To be updated!
  SPI_init( SSPIN2 );  // Only for DRV8301.

  //DRV8302_init( SSPIN2 , 13 ); // Note: pin 13 is also the SCLK pin for communication with DRV8301 and the LED.
  xbar_init();
  adc_init();
  adc_etc_init();
  flexpwm2_init();
  flexpwm4_init();
  syncflexpwm();
  Encoders_init();

  FLEXPWM2_OUTEN |= FLEXPWM_OUTEN_PWMA_EN( 7 ); // Activate all A channels
  FLEXPWM4_OUTEN |= FLEXPWM_OUTEN_PWMA_EN( 7 ); // Activate all A channels

  delay(1);
  changePWM();

  Serial.begin(1);

  motor.state.setupready = 1;
}

void SPI_init( int SSpin ) {
  SPI.begin();
  SPI.beginTransaction(SPISettings( 10e6 , MSBFIRST, SPI_MODE1)); //DRV8301 specsheet: 100 ns -> 10 Mhz. Set correct mode (fallingedgeof the clock).
  pinMode(SSpin, OUTPUT);
  int receivedVal16 = 0;
  while (receivedVal16 != 0x1038) {
    //while (receivedVal16 != 0x1008) {
    digitalWrite(SSpin, LOW);
    receivedVal16 = SPI.transfer16( (0 << 15) | (0x02 << 11) | (1 << 5) | (1 << 4) | (1 << 3) ); //Set 3 PWM inputs mode, disable OC mode
    //receivedVal16 = SPI.transfer16( (0 << 15) | (0x02 << 11)  | (1 << 3) ); //Set 3 PWM inputs mode
    digitalWrite(SSpin, HIGH);
    digitalWrite(SSpin, LOW);
    receivedVal16 = SPI.transfer16( (1 << 15) | (0x02 << 11)  ); // Read register two
    digitalWrite(SSpin, HIGH);
    digitalWrite(SSpin, LOW);
    receivedVal16 = SPI.transfer16( (1 << 15) ); // Get the data
    digitalWrite(SSpin, HIGH);
  }
  SPI.endTransaction();
}

void DRV8302_init( int M_PWM_pin , int OC_ADJ_pin ) {
  pinMode( M_PWM_pin , OUTPUT);
  digitalWrite( M_PWM_pin , 1);
  pinMode( OC_ADJ_pin , OUTPUT);
  digitalWrite( OC_ADJ_pin , 1);
}

void xbar_init() {
  CCM_CCGR2 |= CCM_CCGR2_XBAR1(CCM_CCGR_ON);   //turn clock on for xbara1
  xbar_connect(XBARA1_IN_FLEXPWM2_PWM1_OUT_TRIG0, XBARA1_OUT_ADC_ETC_TRIG00); //FlexPWM to adc_etc
}

void adc_init() {
  //Tried many configurations, but this seems to be best:
  ADC1_CFG =   ADC_CFG_OVWREN       //Allow overwriting of the next converted Data onto the existing
               | ADC_CFG_ADICLK(0)    // input clock select - IPG clock
               | ADC_CFG_MODE(2)      // 12-bit conversion 0 8-bit conversion 1 10-bit conversion 2  12-bit conversion
               | ADC_CFG_ADIV(2)      // Input clock / 4
               | ADC_CFG_ADSTS(0)     // Sample period (ADC clocks) = 3 if ADLSMP=0b
               | ADC_CFG_ADHSC        // High speed operation
               | ADC_CFG_ADTRG;       // Hardware trigger selected
  ADC2_CFG = ADC1_CFG;

  CORE_PIN14_PADCONFIG &= ~ (1 << 12) ; // disable keeper pin for analog input, as per manual
  CORE_PIN15_PADCONFIG &= ~ (1 << 12) ; // disable keeper pin for analog input, as per manual
  CORE_PIN16_PADCONFIG &= ~ (1 << 12) ; // disable keeper pin for analog input, as per manual
  CORE_PIN17_PADCONFIG &= ~ (1 << 12) ; // disable keeper pin for analog input, as per manual
  CORE_PIN18_PADCONFIG &= ~ (1 << 12) ; // disable keeper pin for analog input, as per manual
  CORE_PIN19_PADCONFIG &= ~ (1 << 12) ; // disable keeper pin for analog input, as per manual
  CORE_PIN20_PADCONFIG &= ~ (1 << 12) ; // disable keeper pin for analog input, as per manual
  CORE_PIN21_PADCONFIG &= ~ (1 << 12) ; // disable keeper pin for analog input, as per manual

  CORE_PIN24_PADCONFIG &= ~ (1 << 12) ; // disable keeper pin for analog input, as per manual
  CORE_PIN25_PADCONFIG &= ~ (1 << 12) ; // disable keeper pin for analog input, as per manual
  CORE_PIN26_PADCONFIG &= ~ (1 << 12) ; // disable keeper pin for analog input, as per manual

  //Calibration of ADC
  ADC1_GC |= ADC_GC_CAL;   // begin cal ADC1
  while (ADC1_GC & ADC_GC_CAL) ;
  ADC2_GC |= ADC_GC_CAL;   // begin cal ADC2
  while (ADC2_GC & ADC_GC_CAL) ;

  ADC1_HC0 = 16;   // ADC_ETC channel
  ADC2_HC0 = 16;
}

void adc_etc_init() {
  /* Must disable software reset first */
  ADC_ETC_CTRL &= ~(1 << 31); // SOFTRST

  /* Must clear ADC_ETC_CTRL_TSC_BYPASS bit if using ADC2 */
  ADC_ETC_CTRL &= ~(1 << 30); // TSC_BYPASS

  /* Enable the external XBAR trigger0 and trigger1. Trigger4 uses sync mode to get triggered */
  ADC_ETC_CTRL |= 1;  // TRIG_ENABLE

  ADC_ETC_TRIG0_CTRL = ADC_ETC_TRIG_CTRL_TRIG_CHAIN(2); //TRIG chain length (0->1, 1->2, etc)

  ADC_ETC_TRIG0_CHAIN_1_0 =
    ADC_ETC_TRIG_CHAIN_IE1(0) |
    ADC_ETC_TRIG_CHAIN_B2B1 |
    ADC_ETC_TRIG_CHAIN_HWTS1(1) |
    ADC_ETC_TRIG_CHAIN_CSEL1(1) |
    ADC_ETC_TRIG_CHAIN_IE0(0) |
    ADC_ETC_TRIG_CHAIN_B2B0 |
    ADC_ETC_TRIG_CHAIN_HWTS0(1) |
    ADC_ETC_TRIG_CHAIN_CSEL0(12);

  ADC_ETC_TRIG0_CHAIN_3_2 =
    ADC_ETC_TRIG_CHAIN_IE0(1) |
    ADC_ETC_TRIG_CHAIN_B2B0 |
    ADC_ETC_TRIG_CHAIN_HWTS0(1) |
    ADC_ETC_TRIG_CHAIN_CSEL0(11);

  ADC_ETC_TRIG4_CTRL = ADC_ETC_TRIG_CTRL_TRIG_CHAIN(2) | ADC_ETC_TRIG_CTRL_SYNC_MODE; //TRIG chain length (0->1, 1->2, etc), turn on sync mode
  ADC_ETC_TRIG4_CHAIN_1_0 =
    ADC_ETC_TRIG_CHAIN_IE1(0) |
    ADC_ETC_TRIG_CHAIN_B2B1 |
    ADC_ETC_TRIG_CHAIN_HWTS1(1) |
    ADC_ETC_TRIG_CHAIN_CSEL1(3) |
    ADC_ETC_TRIG_CHAIN_IE0(0) |
    ADC_ETC_TRIG_CHAIN_B2B0 |
    ADC_ETC_TRIG_CHAIN_HWTS0(1) |
    ADC_ETC_TRIG_CHAIN_CSEL0(8);

  ADC_ETC_TRIG4_CHAIN_3_2 =
    ADC_ETC_TRIG_CHAIN_IE0(2) |
    ADC_ETC_TRIG_CHAIN_B2B0 |
    ADC_ETC_TRIG_CHAIN_HWTS0(1) |
    ADC_ETC_TRIG_CHAIN_CSEL0(0);

  attachInterruptVector(IRQ_ADC_ETC0, adcetc0_isr);
  NVIC_ENABLE_IRQ(IRQ_ADC_ETC0);
  attachInterruptVector(IRQ_ADC_ETC1, adcetc1_isr);
  NVIC_ENABLE_IRQ(IRQ_ADC_ETC1);
}

void flexpwm2_init() {     //set PWM
  FLEXPWM2_MCTRL |= FLEXPWM_MCTRL_CLDOK( 7 );//  Clear Load Okay LDOK(SM) -> no reload of PWM settings
  FLEXPWM2_SM0CTRL = FLEXPWM_SMCTRL_FULL | FLEXPWM_SMCTRL_HALF | FLEXPWM_SMCTRL_PRSC(0); //Fixed at no prescaler. Prescaler is only usefull for slow PWM
  FLEXPWM2_SM1CTRL = FLEXPWM_SMCTRL_FULL | FLEXPWM_SMCTRL_HALF | FLEXPWM_SMCTRL_PRSC(0); //Fixed at no prescaler. Prescaler is only usefull for slow PWM
  FLEXPWM2_SM2CTRL = FLEXPWM_SMCTRL_FULL | FLEXPWM_SMCTRL_HALF | FLEXPWM_SMCTRL_PRSC(0); //Fixed at no prescaler. Prescaler is only usefull for slow PWM
  FLEXPWM2_SM0VAL1 = (uint32_t)((float)F_BUS_ACTUAL / F_PWM - 1) / 2; //Set the modulus value (dictates the frequency)
  FLEXPWM2_SM1VAL1 = FLEXPWM2_SM0VAL1;  //Set the modulus value (dictates the frequency)
  FLEXPWM2_SM2VAL1 = FLEXPWM2_SM0VAL1;  //Set the modulus value (dictates the frequency)
  FLEXPWM2_SM0INIT = -FLEXPWM2_SM0VAL1; //Good for center aligned PWM, see manual
  FLEXPWM2_SM1INIT = -FLEXPWM2_SM1VAL1; //Good for center aligned PWM, see manual
  FLEXPWM2_SM2INIT = -FLEXPWM2_SM2VAL1; //Good for center aligned PWM, see manual

  FLEXPWM2_SM0VAL3 = 0; //Start with 0 to avoid glitch at startup
  FLEXPWM2_SM0VAL2 = 0;
  FLEXPWM2_SM1VAL3 = 0;
  FLEXPWM2_SM1VAL2 = 0;
  FLEXPWM2_SM2VAL3 = 0;
  FLEXPWM2_SM2VAL2 = 0;

  //int adc_shift = 0; //New idea. Do not shift the ADC. Probably the ADC takes a quick sample of the signal at the right moment, rest of the time is to get the value.
  //Back to old idea of shifting. Current measurements are better this way (less issue when high duty cycle:
  const int adc_shift = 0; //Tuned by making it finish at the switch moment, then divide offset by 2.

  FLEXPWM2_SM0VAL4 = 0 + adc_shift; // adc trigger 1
  FLEXPWM2_SM0VAL5 = FLEXPWM2_SM0VAL1 + adc_shift; // adc trigger 2

  //FLEXPWM2_SM2VAL4 = FLEXPWM2_SM0VAL4; // adc trigger 1 to show on digital output 9
  //FLEXPWM2_SM2VAL5 = FLEXPWM2_SM0VAL5; // adc trigger 2 to show on digital output 9

  FLEXPWM2_MCTRL |= FLEXPWM_MCTRL_LDOK( 7 );// Load Okay LDOK(SM) -> reload setting again

  //This triggers twice per PWM cycle:
  FLEXPWM2_SM0TCTRL = FLEXPWM_SMTCTRL_OUT_TRIG_EN(1 << 4) | FLEXPWM_SMTCTRL_OUT_TRIG_EN(1 << 5); //  val 4 of Flexpwm sm0 as trigger; #define FLEXPWM_SMTCTRL_OUT_TRIG_EN(n)   ((uint16_t)(((n) & 0x3F) << 0))
  //This triggers once per PWM cycle:
  //FLEXPWM2_SM0TCTRL = FLEXPWM_SMTCTRL_OUT_TRIG_EN(1 << 5); //  val 4 of Flexpwm sm0 as trigger; #define FLEXPWM_SMTCTRL_OUT_TRIG_EN(n)   ((uint16_t)(((n) & 0x3F) << 0))

  *(portConfigRegister(4)) = 1; //Set port 4 to the right mux value (found in pwm.c)
  *(portConfigRegister(5)) = 1; //Set port 5 to the right mux value (found in pwm.c)
  *(portConfigRegister(6)) = 2; //Set port 6 to the right mux value (found in pwm.c)

  //FLEXPWM2_OUTEN |= FLEXPWM_OUTEN_PWMB_EN( 4 ); // Activate B channel
  //*(portConfigRegister(9)) = 2; //Set port 9 to the right mux value (found in pwm.c)
}

void flexpwm4_init() {     //set PWM
  FLEXPWM4_MCTRL |= FLEXPWM_MCTRL_CLDOK( 7 );//  Clear Load Okay LDOK(SM) -> no reload of PWM settings
  FLEXPWM4_SM0CTRL = FLEXPWM_SMCTRL_FULL | FLEXPWM_SMCTRL_HALF | FLEXPWM_SMCTRL_PRSC(0); //Fixed at no prescaler. Prescaler is only usefull for slow PWM
  FLEXPWM4_SM1CTRL = FLEXPWM_SMCTRL_FULL | FLEXPWM_SMCTRL_HALF | FLEXPWM_SMCTRL_PRSC(0); //Fixed at no prescaler. Prescaler is only usefull for slow PWM
  FLEXPWM4_SM2CTRL = FLEXPWM_SMCTRL_FULL | FLEXPWM_SMCTRL_HALF | FLEXPWM_SMCTRL_PRSC(0); //Fixed at no prescaler. Prescaler is only usefull for slow PWM
  FLEXPWM4_SM0VAL1 = (uint32_t)((float)F_BUS_ACTUAL / F_PWM - 1) / 2; //Set the modulus value (dictates the frequency)
  FLEXPWM4_SM1VAL1 = FLEXPWM4_SM0VAL1;  //Set the modulus value (dictates the frequency)
  FLEXPWM4_SM2VAL1 = FLEXPWM4_SM0VAL1;  //Set the modulus value (dictates the frequency)
  FLEXPWM4_SM0INIT = -FLEXPWM4_SM0VAL1; //Good for center aligned PWM, see manual
  FLEXPWM4_SM1INIT = -FLEXPWM4_SM1VAL1; //Good for center aligned PWM, see manual
  FLEXPWM4_SM2INIT = -FLEXPWM4_SM2VAL1; //Good for center aligned PWM, see manual

  FLEXPWM4_SM0VAL3 = 0; //Start with 0 to avoid glitch at startup
  FLEXPWM4_SM0VAL2 = 0;
  FLEXPWM4_SM1VAL3 = 0;
  FLEXPWM4_SM1VAL2 = 0;
  FLEXPWM4_SM2VAL3 = 0;
  FLEXPWM4_SM2VAL2 = 0;

  //int adc_shift = 0; //New idea. Do not shift the ADC. Probably the ADC takes a quick sample of the signal at the right moment, rest of the time is to get the value.
  //Back to old idea of shifting. Current measurements are better this way (less issue when high duty cycle:
  const int adc_shift = 0; //Tuned by making it finish at the switch moment, then divide offset by 2.

  FLEXPWM4_SM0VAL4 = 0 + adc_shift; // adc trigger 1
  FLEXPWM4_SM0VAL5 = FLEXPWM4_SM0VAL1 + adc_shift; // adc trigger 2

  FLEXPWM4_MCTRL |= FLEXPWM_MCTRL_LDOK( 7 );// Load Okay LDOK(SM) -> reload setting again

  *(portConfigRegister(22)) = 1; //Set port 22 to the right mux value (found in pwm.c)
  *(portConfigRegister(23)) = 1; //Set port 23 to the right mux value (found in pwm.c)
  *(portConfigRegister(2)) = 1; //Set port 2 to the right mux value (found in pwm.c)
}

void syncflexpwm() {
  cli()
  //Set CTRL2 to the normal settings:
  FLEXPWM2_SM0CTRL2 = FLEXPWM_SMCTRL2_INDEP; //Enable Independent pair, but disable Debug Enable and WAIT Enable. When set to one, the PWM will continue to run while the chip is in debug/WAIT mode.
  FLEXPWM2_SM1CTRL2 = FLEXPWM_SMCTRL2_INDEP; //Enable Independent pair, but disable Debug Enable and WAIT Enable. When set to one, the PWM will continue to run while the chip is in debug/WAIT mode.
  FLEXPWM2_SM2CTRL2 = FLEXPWM_SMCTRL2_INDEP; //Enable Independent pair, but disable Debug Enable and WAIT Enable. When set to one, the PWM will continue to run while the chip is in debug/WAIT mode.
  FLEXPWM4_SM0CTRL2 = FLEXPWM_SMCTRL2_INDEP; //Enable Independent pair, but disable Debug Enable and WAIT Enable. When set to one, the PWM will continue to run while the chip is in debug/WAIT mode.
  FLEXPWM4_SM1CTRL2 = FLEXPWM_SMCTRL2_INDEP; //Enable Independent pair, but disable Debug Enable and WAIT Enable. When set to one, the PWM will continue to run while the chip is in debug/WAIT mode.
  FLEXPWM4_SM2CTRL2 = FLEXPWM_SMCTRL2_INDEP; //Enable Independent pair, but disable Debug Enable and WAIT Enable. When set to one, the PWM will continue to run while the chip is in debug/WAIT mode.

  FLEXPWM2_SM0CTRL2 |= FLEXPWM_SMCTRL2_FRCEN;  // pin 4
  FLEXPWM2_SM1CTRL2 |= FLEXPWM_SMCTRL2_INIT_SEL(2); // pin 5 Master sync from submodule 0 causes initialization.
  FLEXPWM2_SM2CTRL2 |= FLEXPWM_SMCTRL2_INIT_SEL(2); // pin 6 Master sync from submodule 0 causes initialization.

  FLEXPWM4_SM0CTRL2 |= FLEXPWM_SMCTRL2_FRCEN; // pin 22
  FLEXPWM4_SM1CTRL2 |= FLEXPWM_SMCTRL2_INIT_SEL(2); // pin 23 Master sync from submodule 0 causes initialization.
  FLEXPWM4_SM2CTRL2 |= FLEXPWM_SMCTRL2_INIT_SEL(2); // pin 2 Master sync from submodule 0 causes initialization.

  //Sync flexpwm2 and flexpwm4
  FLEXPWM2_SM0CTRL2 |= FLEXPWM_SMCTRL2_FORCE; // Force FlexPWM2
  FLEXPWM4_SM0CTRL2 |= FLEXPWM_SMCTRL2_FORCE; // Force FlexPWM4. This is about 50 ns later than force of flexpwm2. No idea on how to improve this

  sei();
}

void Encoders_init() {
  Encoder1.setInitConfig();
  Encoder1.EncConfig.filterCount = 3; //Bit of filtering to avoid spurious triggering.
  Encoder1.EncConfig.filterSamplePeriod = 3; //Bit of filtering to avoid spurious triggering.
  Encoder1.EncConfig.INDEXTriggerMode  = 1;
  Encoder1.EncConfig.IndexTrigger  = 1;
  Encoder1.EncConfig.positionInitialValue = 0;
  Encoder1.init();

  Encoder2.setInitConfig();
  Encoder2.EncConfig.filterCount = 3; //Bit of filtering to avoid spurious triggering.
  Encoder2.EncConfig.filterSamplePeriod = 3; //Bit of filtering to avoid spurious triggering.
  Encoder2.EncConfig.INDEXTriggerMode = 1;
  Encoder2.EncConfig.IndexTrigger  = 1;
  Encoder2.EncConfig.positionInitialValue = 0;
  Encoder2.init();
}

//////////////////////////////////////////////////////////////////////////////////
////// Start of the real time code, everything runs in the adc interrupts.  //////
//////////////////////////////////////////////////////////////////////////////////

void loop() {
  //Moved sending of names to a slow loop to avoid overloads
  if (sendnames == true) {
    for (uint32_t i = 0; i < sizeof(trace.all_pointers) / sizeof(trace.all_pointers[0]) ; i ++) {
      if ( trace.names[i] == NULL) {
        break;
      }
      Serial.println( trace.names[i] );
      delayMicroseconds(200);
      Serial.println( trace.all_types[i] );
      delayMicroseconds(200);
      Serial.println( trace.all_lengths[i] / signaltomemberlength(i) );
      delayMicroseconds(200);
    }
    sendnames = false;
  }
  delay(1);
}

void adcetc0_isr() {
  ADC_ETC_DONE0_1_IRQ &= 1;   // clear
}

void adcetc1_isr() {
  ADC_ETC_DONE0_1_IRQ &= 1 << 20;   // clear
  motor.state.prevtime = motor.state.curtime;
  motor.state.curtime = micros();
  if (motor.state.prevtime == 0) {
    motor.state.prevtime = motor.state.curtime;
  }
  if ((motor.state.curtime - motor.state.prevtime) > (motor.conf.Ts + 3)) {
    motor.state.overloadcounter += 1;
  }
  motor.state.is_v7 = (FLEXPWM2_SM0STS & FLEXPWM_SMSTS_CMPF(2));  //is_v7 = True when in v7
  FLEXPWM2_SM0STS |= FLEXPWM_SMSTS_CMPF(2); //Reset flag

  //ADC1:
  motor.state.sens1 = (ADC_ETC_TRIG0_RESULT_1_0 & 4095) * 0.0008058608; // 4095.0 * 3.3;
  motor.state.sens3 = ((ADC_ETC_TRIG0_RESULT_1_0 >> 16) & 4095) * 0.0008058608; // 4095.0 * 3.3;
  motor.state.sensBus = (ADC_ETC_TRIG0_RESULT_3_2 & 4095) * motor.conf.Busadc2Vbus;   // 4095.0 * 3.3 * ((68.3+5.05)/5.05);
  LOWPASS( motor.state.sensBus_lp , motor.state.sensBus, 0.1 ); //1000 Hz when running at 60 kHz

  //ADC2:
  motor.state.sens2 = (ADC_ETC_TRIG4_RESULT_1_0 & 4095) * 0.0008058608; // 4095.0 * 3.3;
  motor.state.sens4 = ((ADC_ETC_TRIG4_RESULT_1_0 >> 16) & 4095) * 0.0008058608; // 4095.0 * 3.3;
  motor.state.sensBus2 = (ADC_ETC_TRIG4_RESULT_3_2 & 4095) * motor.conf.Busadc2Vbus;   // 4095.0 * 3.3 * ((68.3+5.05)/5.05);

  // Calculate currents (links sensors to axes, to be improved)
  motor.state1.ia = motor.conf1.adc2A * (motor.state.sens1 - motor.state.sens1_calib);
  motor.state1.ib = motor.conf1.adc2A * (motor.state.sens2 - motor.state.sens2_calib);
  motor.state1.ic = -motor.state1.ia - motor.state1.ib;

  motor.state2.ia = motor.conf2.adc2A * (motor.state.sens3 - motor.state.sens3_calib);
  motor.state2.ib = motor.conf2.adc2A * (motor.state.sens4 - motor.state.sens4_calib);
  motor.state2.ic = -motor.state2.ia - motor.state2.ib;

  //
  //  if ( motor.state.sensBus > motor.conf.V_Bus + 1 ) {
  //    //    digitalWrite( CHOPPERPIN , HIGH);
  //  }
  //  else {
  //    //    digitalWrite( CHOPPERPIN , LOW);
  //  }

  if ( motor.state.sensBus > 45 or motor.state.sensBus2 > 45 ) {
    error(41 , &motor.state1);
  }
  if ( motor.state.sensBus2 > 45  ) {
    error(41 , &motor.state2);
  }

  if (motor.state.setupready == 1) {
    if (motor.state.n_senscalib < 1e4) {
      // Have to check this. Calibration not always ok.
      motor.state.n_senscalib++;
      motor.state.sens1_calib += motor.state.sens1;
      motor.state.sens2_calib += motor.state.sens2;
      motor.state.sens3_calib += motor.state.sens3;
      motor.state.sens4_calib += motor.state.sens4;
    }
    else if (motor.state.n_senscalib == 1e4) {
      motor.state1.OutputOn = true;
      motor.state2.OutputOn = true;
      motor.state.sens1_calib /= motor.state.n_senscalib;
      motor.state.sens2_calib /= motor.state.n_senscalib;
      motor.state.sens3_calib /= motor.state.n_senscalib;
      motor.state.sens4_calib /= motor.state.n_senscalib;
      motor.state.n_senscalib++;
    }
    else {
      updateDisturbance(); //Switched this before readENC to have a fresher encoder position
      GenSetpoint( &motor.conf1 , &motor.state1 , SPprofile1 );
      GenSetpoint( &motor.conf2 , &motor.state2 , SPprofile2 );
      readENC();
      Control( &motor.conf1 , &motor.state1 , Biquads1);
      Control( &motor.conf2 , &motor.state2 , Biquads2);
      Transforms( &motor.conf1 , &motor.state1 , Biquads1);
      Transforms( &motor.conf2 , &motor.state2 , Biquads2);

      current_and_duty_limts( &motor.conf1 , &motor.state1 );
      current_and_duty_limts( &motor.conf2 , &motor.state2 );
      changePWM();
      communicationProcess();
      processCommands( &motor.conf1 , &motor.state1);
      processCommands( &motor.conf2 , &motor.state2);
      motor.state.curloop++;
    }
  }
}
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

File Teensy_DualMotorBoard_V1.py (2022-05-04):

#%%
# -*- coding: utf-8 -*-
"""
Created on Sat Sep 29 19:25:07 2018

@author: Elwin
"""

from os import chdir
chdir('c:\\users\\elwin\\desktop\\python')


import serial
import numpy as np
from scipy import signal as sig
import matplotlib.pyplot as plt
import matplotlib.ticker as tickercom
import struct
import warnings
import matplotlib.cbook
import time
import make3
import math
import pandas as pd
from tqdm import tqdm
import time
import random
import pyqtgraph as pg
from collections import deque
from pyqtgraph.Qt import QtGui, QtCore

plt.rcParams["figure.dpi"] = 200

from PyQt5.QtWidgets import (
    QApplication,
    QGridLayout,
    QPushButton,
    QWidget,
)

f_pwm = 30e3
Ts = 1/(2*f_pwm)

n_trace = 14; #Was 10. USB packets are up to 2048 kB. 4 B per value -> 512 values. 16 (14 + 2 overhead)values fit exactly 32 times in this 512 values. 
# n_trace = 30; 
# n_trace = 62;  #Too high, current plant prbs measurement shows it is not always in time

# com = 'COM10' 1
com = 'COM3'

motor = 'motor1'


#for i in tqdm(range(10)):
#    time.sleep(0.1)

global ser

try:
    ser = serial.Serial( com  , timeout= 0.1)  # open serial port
    print(ser.name)         # check which port was really used
except:
    print(ser.name)         # check which port was really used

from numpy import (atleast_1d, poly, polyval, roots, real, asarray,
                   resize, pi, absolute, logspace, r_, sqrt, tan, log10,
                   arctan, arcsinh, sin, cos, exp, cosh, arccosh, ceil, conjugate,
                   zeros, sinh, append, concatenate, prod, ones, array,
                   mintypecode)
from numpy.polynomial.polynomial import polyval as npp_polyval
warnings.filterwarnings("ignore",category=matplotlib.cbook.mplDeprecation)

def tracesignal( signals, t ,plot=True):
    setTrace( signals )
    t,s = readData( int(t /Ts) )
    if plot:
        plt.figure();
        plt.plot(t,s[:,0:len(signals)], );
        plt.legend( signals )
        plt.show()
    return t,s[:,0:len(signals)]


def bode( H ,f  , name = '' , title = 'bode plot'):
    mag = np.abs( H )
    phase = np.angle( H )
    ax1 = plt.subplot(2,1,1)
#    plt.loglog(f, mag)    # Bode magnitude plot
    plt.semilogx(f, 20*np.log10(mag) , label = name)    # Bode magnitude plot
    plt.grid( 1 , 'both' , 'both')
    plt.ylabel('Magnitude [dB]')
    plt.title(title)
    plt.legend()
#    ax1.xaxis.set_minor_formatter(ticker.ScalarFormatter())
    ax2 = plt.subplot(2,1,2, sharex=ax1)
    plt.plot(f, phase * 180 / np.pi)  # Bode phase plot
    plt.grid( 1 , 'both')
    plt.xlabel('Frequency [Hz]')
    plt.ylabel('Phase [deg]')
    plt.ylim( -182, 182)
    plt.tight_layout()
    plt.show()   

def restart( ser=ser ):
    ser.write( b'o' + struct.pack('f',  0) ) # Restart controller

def setcont( contnum ):
    ser.write( b'C' + struct.pack('I',  contnum ) )

def moverel( pos ):
    p = pos
    v = 30*np.pi
    a = 300*np.pi
    j = 40000*np.pi
    [t1, t2, t3, jd] = prepSP(  p , v , a , j )
    ser.write( b'p' + struct.pack('f',  0) )
    ser.write( b'p' + struct.pack('f',  0) )

def moveabs( pos ):
    posrel = pos - getsig('rmech')
    if posrel != 0:
        moverel( posrel )

def nyquist( H ,f  , name = '' , title = 'nyquist plot'):
    plt.plot( np.real( H ) , np.imag( H ) , label = name)    # Bode magnitude plot
    tmp = 0.5 * np.exp( -1j * np.arange( 0 , 2*np.pi , 0.01) ) - 1
    plt.plot( np.real( tmp ) , np.imag( tmp ) , label = '6 dB')    # Bode magnitude plot
    plt.grid( 1 , 'both')
    plt.title(title)
    plt.legend()
    plt.xlabel('Real')
    plt.ylabel('Imaginary')
    plt.xlim( -2 , 2)
    plt.ylim( -2 , 2)
    plt.tight_layout()
    plt.show()


def freqrespd( num , den ,f , Ts ):
    zm1 = exp(-1j * 2*np.pi * f*Ts )
    H = (npp_polyval(zm1, num, tensor=False) / npp_polyval(zm1, den, tensor=False))
    return H
   
def leadlag( fBW , alpha1, alpha2, Ts):
    fs = 1/Ts
    alpha = np.sqrt( 1/ alpha2**2 + 1 ) / np.sqrt( alpha1**2 + 1 )
    w0 = fBW * 2 * np.pi / alpha1
    wp = fBW * 2 * np.pi * alpha2
    a1 = (wp -2*fs) / (wp + 2*fs)
    b0 = alpha * ( ( 1 + 2*fs/w0 ) / ( 1 + 2*fs/wp ))
    b1 = alpha * ( ( 1 - 2*fs/w0 ) / ( 1 + 2*fs/wp ))
    num = [b0 , b1]
    den = [1 , a1]
    return num, den

def lowpass2( f0, damp,  Ts):
    w0 = 2 * np.pi * f0 * Ts
    alpha =sin(w0) * damp
    b0 = 0.5 * (1 - cos(w0)) / (1 + alpha) 
    b1 = 2 * b0
    b2 = b0 
    a1 = (-2 * cos(w0)) / (1 + alpha)
    a2 = (1 - alpha) / (1 + alpha)
    num = [b0 , b1, b2]
    den = [1  , a1, a2]
    return num, den

def Integrator( f0, Ts):
    b0 = f0 * 2 * pi * Ts/2
    b1 = b0
    num = [b0, b1]
    den = [1  , -1]
    return num, den
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

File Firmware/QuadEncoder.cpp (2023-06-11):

#include "Arduino.h"
#include "QuadEncoder.h"

//#define DEBUG_OUTPUT

const QuadEncoder::ENC_Channel_t QuadEncoder::channel[] = {	
	{0,&IMXRT_ENC1, IRQ_ENC1, isrEnc1, 66, 67, 68, 69, 70,&CCM_CCGR4,CCM_CCGR4_ENC1(CCM_CCGR_ON)},  //this is a dummy entry - use 1-4 for channels
	{1, &IMXRT_ENC1, IRQ_ENC1, isrEnc1, 66, 67, 68, 69, 70,&CCM_CCGR4,CCM_CCGR4_ENC1(CCM_CCGR_ON)},
	{2, &IMXRT_ENC2, IRQ_ENC2, isrEnc2, 71, 72, 73, 74, 75,&CCM_CCGR4,CCM_CCGR4_ENC2(CCM_CCGR_ON)},
	{3, &IMXRT_ENC3, IRQ_ENC3, isrEnc3, 76, 77, 78, 79, 80,&CCM_CCGR4,CCM_CCGR4_ENC3(CCM_CCGR_ON)},
	{4, &IMXRT_ENC4, IRQ_ENC4, isrEnc4, 81, 82, 83, 84, 85,&CCM_CCGR4,CCM_CCGR4_ENC4(CCM_CCGR_ON)}
};
const uint8_t QuadEncoder::_channel_count =  (sizeof(QuadEncoder::channel)/sizeof(QuadEncoder::channel[0]));

//xbara1 pin config
// idx, pin, *reg, alt,xbarIO, xbarMUX

#if defined( ARDUINO_TEENSY40)
const  QuadEncoder::ENC_Hardware_t QuadEncoder::hardware[] = {	
	{0, 0, &CORE_XIO_PIN0, 1, 17, 1},	{1, 1, &CORE_XIO_PIN1, 1, 16, 0},
	{2, 2, &CORE_XIO_PIN2, 3, 6, 0},	{3, 3, &CORE_XIO_PIN3, 3, 7, 0},
	{4, 4, &CORE_XIO_PIN4,3, 8, 0},		{5, 5, &CORE_XIO_PIN5, 3, 17, 0},
	{6, 7, &CORE_XIO_PIN7, 1, 15, 1},	{8, 8, &CORE_XIO_PIN8, 1, 14, 1},
	{8, 30, &CORE_XIO_PIN30, 1, 23, 0},	{9, 31, &CORE_XIO_PIN31, 1, 22, 0},
	{10, 33, &CORE_XIO_PIN33, 3, 9, 0}
};
#endif
#ifdef ARDUINO_TEENSY41
const  QuadEncoder::ENC_Hardware_t QuadEncoder::hardware[] = {	
	{0, 0, &CORE_XIO_PIN0, 1, 17, 1},	{1, 1, &CORE_XIO_PIN1, 1, 16, 0},
	{2, 2, &CORE_XIO_PIN2, 3, 6, 0},	{3, 3, &CORE_XIO_PIN3, 3, 7, 0},
	{4, 4, &CORE_XIO_PIN4,3, 8, 0},		{5, 5, &CORE_XIO_PIN5, 3, 17, 0},
	{6, 7, &CORE_XIO_PIN7, 1, 15, 1},	{7, 8, &CORE_XIO_PIN8, 1, 14, 1},
	{8, 30, &CORE_XIO_PIN30, 1, 23, 0},	{9, 31, &CORE_XIO_PIN31, 1, 22, 0},
	{10, 33, &CORE_XIO_PIN33, 3, 9, 0},	{11, 36, &CORE_XIO_PIN36, 1, 16, 1},
	{12, 37, &CORE_XIO_PIN37, 1, 17, 3}

};
#endif

#if defined( ARDUINO_TEENSY_MICROMOD)
const  QuadEncoder::ENC_Hardware_t QuadEncoder::hardware[] = {	
	{0, 0, &CORE_XIO_PIN0, 1, 17, 1},	{1, 1, &CORE_XIO_PIN1, 1, 16, 0},
	{2, 2, &CORE_XIO_PIN2, 3, 6, 0},	{3, 3, &CORE_XIO_PIN3, 3, 7, 0},
	{4, 4, &CORE_XIO_PIN4,3, 8, 0},		{5, 5, &CORE_XIO_PIN5, 3, 17, 0},
	{6, 7, &CORE_XIO_PIN7, 1, 15, 1},	{7, 8, &CORE_XIO_PIN8, 1, 14, 1},
	{8, 30, &CORE_XIO_PIN30, 1, 23, 0},	{9, 31, &CORE_XIO_PIN31, 1, 22, 0},
	{10, 33, &CORE_XIO_PIN33, 3, 9, 0},	{11, 36, &CORE_XIO_PIN36, 3, 5, 1},
	{12, 37, &CORE_XIO_PIN37, 3, 4, 1}
};
#endif
const uint8_t QuadEncoder::_hardware_count =  (sizeof(QuadEncoder::hardware)/sizeof(QuadEncoder::hardware[0]));

QuadEncoder * QuadEncoder::list[5];

  uint8_t QuadEncoder::compareValueFlag;
 uint32_t QuadEncoder::homeCounter;
 uint32_t QuadEncoder::indexCounter;

 
void QuadEncoder::setInitConfig() {
  getConfig1(&EncConfig);
}

void QuadEncoder::init()
{
  Init(&EncConfig);
  setConfigInitialPosition();
  enableInterrupts(&EncConfig);
}


QuadEncoder::QuadEncoder(uint8_t encoder_ch, uint8_t PhaseA_pin, uint8_t PhaseB_pin, uint8_t pin_pus, uint8_t index_pin, uint8_t home_pin, uint8_t trigger_pin){
	if(encoder_ch >= 0){
	  _encoder_ch = encoder_ch;
	
	CCM_CCGR2 |= CCM_CCGR2_XBAR1(CCM_CCGR_ON);   //turn clock on for xbara1
  
#ifdef DEBUG_OUTPUT
	Serial.printf("begin: encoder channel-> %d\n",_encoder_ch);
	Serial.printf("begin: pinA-> %d, pinB-> %d\n", PhaseA_pin, PhaseB_pin);
#endif
	  if(PhaseA_pin != 255 )
		enc_xbara_mapping(PhaseA_pin, PHASEA, pin_pus);
	  if(PhaseB_pin != 255 )
		enc_xbara_mapping(PhaseB_pin, PHASEB, pin_pus);
	  if(home_pin != 255 )
		 enc_xbara_mapping(home_pin, HOME, pin_pus);
	  if(index_pin != 255 )
		 enc_xbara_mapping(index_pin, INDEX, pin_pus);
	  if(trigger_pin != 255 )
		 enc_xbara_mapping(trigger_pin, TRIGGER, pin_pus);
	} else {
	  Serial.println("No Encoder Channel Selected!");
	}
	
	disableInterrupts(_positionROEnable);
	disableInterrupts(_positionRUEnable);
}

void QuadEncoder::getConfig1(enc_config_t *config)
{
    /* Initializes the configure structure to zero. */
    memset(config, 0, sizeof(*config));

    config->enableReverseDirection = DISABLE;
    config->decoderWorkMode = DISABLE;
    config->HOMETriggerMode = DISABLE;
    config->INDEXTriggerMode = 0;
	config->IndexTrigger = DISABLE;
	config->HomeTrigger = DISABLE;
    config->clearCounter = DISABLE;
    config->clearHoldCounter = DISABLE;
    config->filterCount = 0;
    config->filterSamplePeriod = 0;
    config->positionMatchMode = false;
	config->positionCompareMode = DISABLE;
    config->positionCompareValue = 0xffffffff;
    config->revolutionCountCondition = DISABLE;
    config->enableModuloCountMode = DISABLE;
    config->positionModulusValue = 0;
    config->positionInitialValue = 0;
	config->positionROIE = DISABLE;
	config->positionRUIE = DISABLE;
	
}

void QuadEncoder::printConfig(enc_config_t *config)
{
	Serial.printf("\tenableReverseDirection: %d\n",config->enableReverseDirection);
	Serial.printf("\tdecoderWorkMode: %d\n",config->decoderWorkMode);
	Serial.printf("\tHOMETriggerMode: %d\n",config->HOMETriggerMode);
	Serial.printf("\tINDEXTriggerMode: %d\n",config->INDEXTriggerMode);
	Serial.printf("\tIndexTrigger: %d\n",config->IndexTrigger);
	Serial.printf("\tHomeTrigger: %d\n",config->HomeTrigger);	
	
	Serial.printf("\tclearCounter: %d\n",config->clearCounter);
	Serial.printf("\tclearHoldCounter: %d\n",config->clearHoldCounter);
	
	Serial.printf("\tfilterCount: %d\n",config->filterCount);
	Serial.printf("\tfilterSamplePeriod: %d\n",config->filterSamplePeriod);
	Serial.printf("\tpositionCompareMode: %x\n",config->positionCompareMode);
	Serial.printf("\tpositionCompareValue: %x\n",config->positionCompareValue);
	Serial.printf("\trevolutionCountCondition: %d\n",config->clearCounter);
	Serial.printf("\tenableModuloCountMode: %d\n",config->clearHoldCounter);
	
	Serial.printf("\tpositionInitialValue: %d\n",config->positionInitialValue);
	Serial.printf("\tpositionROIE: %d\n",config->positionROIE);
	Serial.printf("\tpositionRUIE: %x\n",config->positionRUIE);
	Serial.printf("\n");
}

void QuadEncoder::setConfigInitialPosition()
{
    uint16_t tmp16 = channel[_encoder_ch].ENC->CTRL & (uint16_t)(~ENC_CTRL_W1C_FLAGS);

    tmp16 |= ENC_CTRL_SWIP_MASK; /* Write 1 to trigger the command for loading initial position value. */
    channel[_encoder_ch].ENC->CTRL = tmp16;
}
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

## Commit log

2022-03-18 Teensy Dual Motor Control
    First version on GIT
2022-03-18 New current controller: PI with Tustin integrator
2022-03-18 Bugfix Ts should not be an integer, otherwise wrong controller gains when running 60 kHz.
    [Teensy_DualMotorBoard_V1.ino, defines.h]
2022-04-15 Cleanup and fixed warnings
    [Teensy_DualMotorBoard_V1.ino, Teensy_DualMotorBoard_V1.py]
2022-04-17 Increased traceable signals to 30
    Increasing to 62 was too much, prbs current plant showed it was not always in time (noisy phase near nyquist frequency)
    [Teensy_DualMotorBoard_V1.ino, Teensy_DualMotorBoard_V1.py, defines.h]
2022-05-04 Add HFI feedforward and corrected gain
    [Teensy_DualMotorBoard_V1.ino]
2022-05-04 Add power and bus current calculations. Minor cleanup.
2022-05-19 Add PCB design
    [Encoders_input.kicad_sch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]
2022-05-19 Add PDF of PCB schematic
2022-12-27 Large update to use variables in structures. Preparation for simpler dual motor control.
2022-12-27 Changed motor 2 current inputs
    Chosen inputs turned out to not work for analog input.
    [Teensy_DualMotorBoard_V1.ino, defines.h, test.py]
2023-05-28 Changed leadlag to series PID with first order lowpass. Changed Tustin integrators to normal integrators.
2023-05-29 2 Motors now working
2023-06-04 Added Biquad filters to control loops for lowpass and notches
2023-06-04 Fixed initialization of Biquad filters
2023-06-04 Fixed issue where wrong variable was passed to velocity feedforward
    [Teensy_DualMotorBoard_V1.ino]
2023-06-10 Add biquad filters for current controllers
2023-06-10 Encoders minor update
2023-06-10 More setpoint features Offset velocity improved Controller tuning in Python
2023-06-12 Fix current loop integrators Implement getsigid
    [Teensy_DualMotorBoard_V1.ino, test.py]
2023-06-12 Fixed bug that caused traces of 1e6 samples or more not to work
    [Teensy_DualMotorBoard_V1.ino]
2023-06-18 Cleanup Fix small glitch on turning on Corrected voltage feedforward Added streaming functionality to stream setpoint from pc Readall now has option to ignore large arrays
    [GraphAndTree2.py, Teensy_DualMotorBoard_V1.ino, defines.h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]
2023-07-09 Added filtering in parametertree Cleanup
2023-10-09 Object oriented interfacing via motorclass.py Added autocompletion to all variables Added motor object that allows for easy access to all variables (set and get) Tracing of 50 signals @60 kHz
2023-12-27 Added threading and background trace
2023-12-30 Cleanup: Put files in folders and some renaming Make more use of objects Added check before sending data over serial: prevent strange motor behaviour
    [Firmware.ino, GUI.py, GUItesting.py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]
2024-01-06 Added timeout in the connecting to Teensy Changed hfi_abs_pos to double Adjusted rel setpoint option to wait without getsig (such that tracebg can be running)
2024-02-04 Transfer errors no longer cause error, but still avoid crashing Teensy when PC is not reading buffer
    [Firmware.ino]
2024-02-04 Improved HFI: Corrected scaling. Added error clipping. HFI lowpass now works. Added 45 degrees HFI. Added comments.
    [Firmware.ino, defines.h, stream_object.py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]
2024-02-06 Add current offset ramp. Add truncate to stateX->hfi_dir_int to avoid runaway integrator (not too small to not impact startup). Encoder commutation calculation inside 2*pi
    [Firmware.ino, defines.h, stream_object.py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]
2024-12-24 Fix encoder issue that caused issues when enccountperrev/N_pp was not an integer.
    [Firmware.ino]
2024-12-24 Added posibility to enable/disable the usage of V7 (enabled = measure current and run loop twice per PWM cycle (V0 and V7), diabled = once per PWM cycle (V0))
